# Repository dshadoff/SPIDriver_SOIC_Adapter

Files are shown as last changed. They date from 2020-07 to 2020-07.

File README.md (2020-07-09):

# SPIDriver SOIC Adapter board

While most of my boards are basically electrical things with some mechanical aspects,
some of them are primarily mechnical things with some electrical aspects. This board
is one of those.

I have an ExCamera Labs SPIDriver ( https://www.crowdsupply.com/excamera/spidriver ), and
I've been using it to read/write to various types of SPI memory chips; the hookup wires
provided with the unit are certainly multipupose, but they aren't optimized for connection
the SPIDriver to the SOIC in-circuit chip clip.

Before:
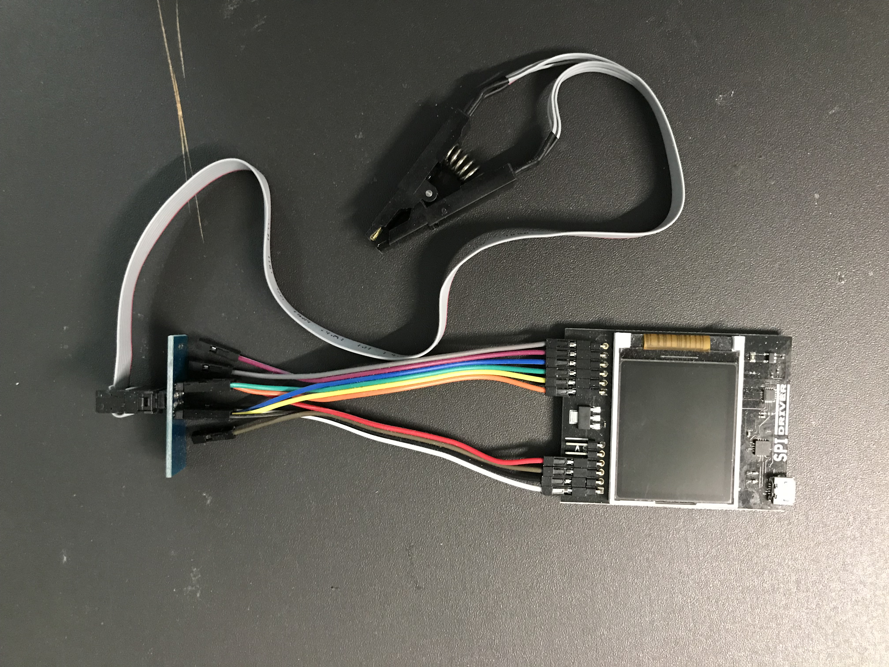
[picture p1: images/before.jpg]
Loose Wires


After:
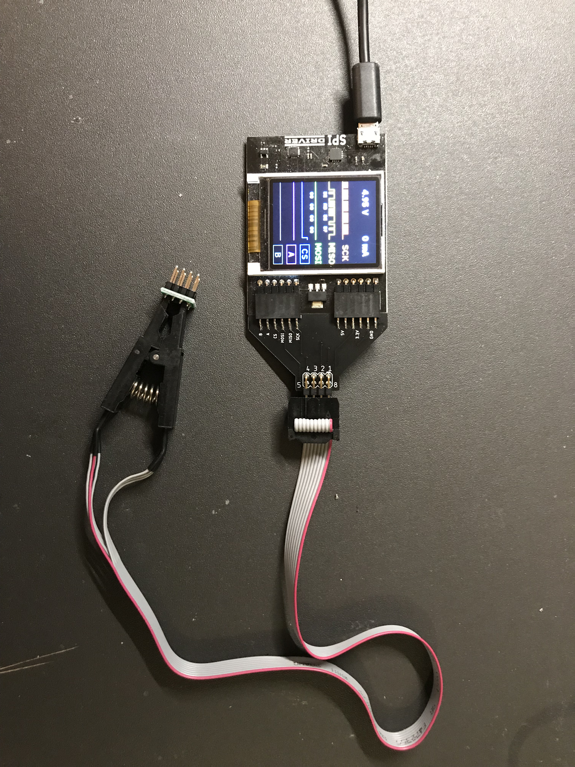
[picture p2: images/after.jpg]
Connector Board


Assembly is simple:
1. First attach the two Harwin M20-7910642R header sockets on the SPIDriver's headers.
(Link to part: https://www.mouser.ca/ProductDetail/Harwin/M20-7910642R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 )

2. Position the PC board right up agains the SPIDriver board, and attach clips to hold
it in place while soldering takes place.

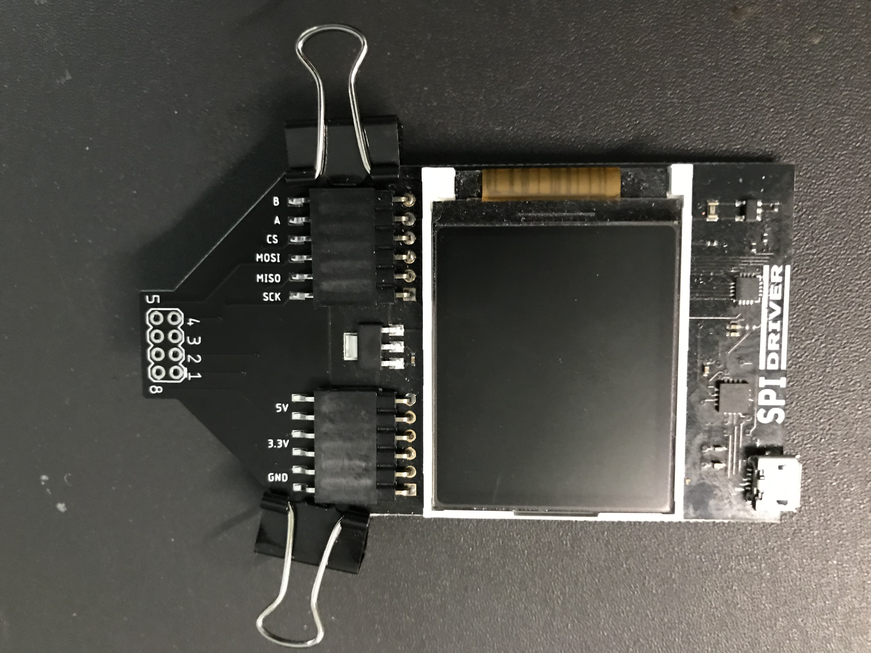
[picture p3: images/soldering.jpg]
Position Board


3. Add the 2-row headers and solder them in place.

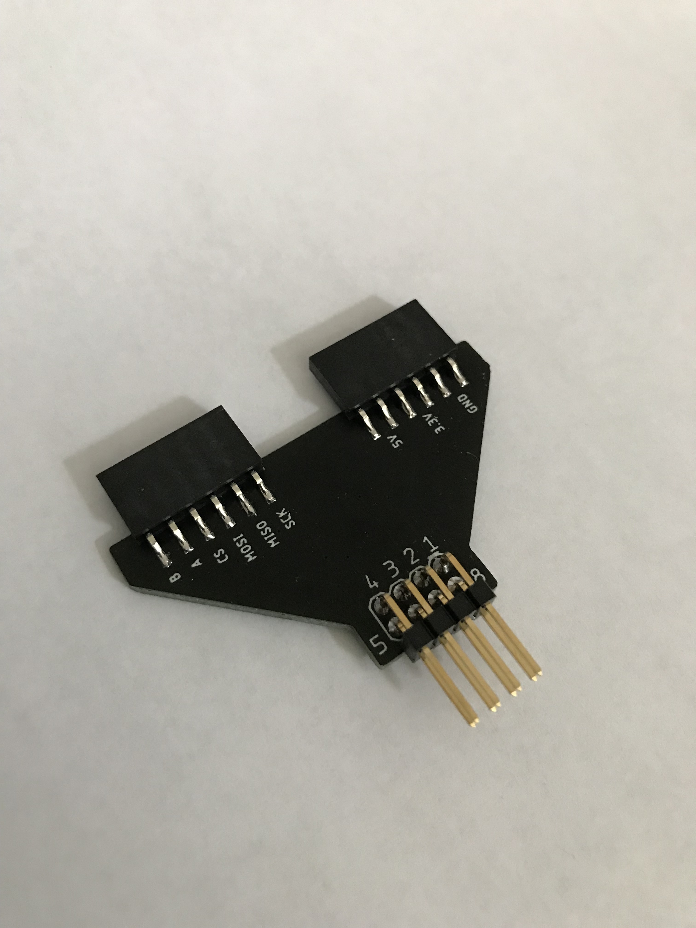
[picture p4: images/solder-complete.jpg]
Completed Board


I designed the board using the free version of EAGLE (2-layer, less than 100mm on both
X- and Y-axes).  The gerbers are included in this repository, in case you want to get your
own set made.

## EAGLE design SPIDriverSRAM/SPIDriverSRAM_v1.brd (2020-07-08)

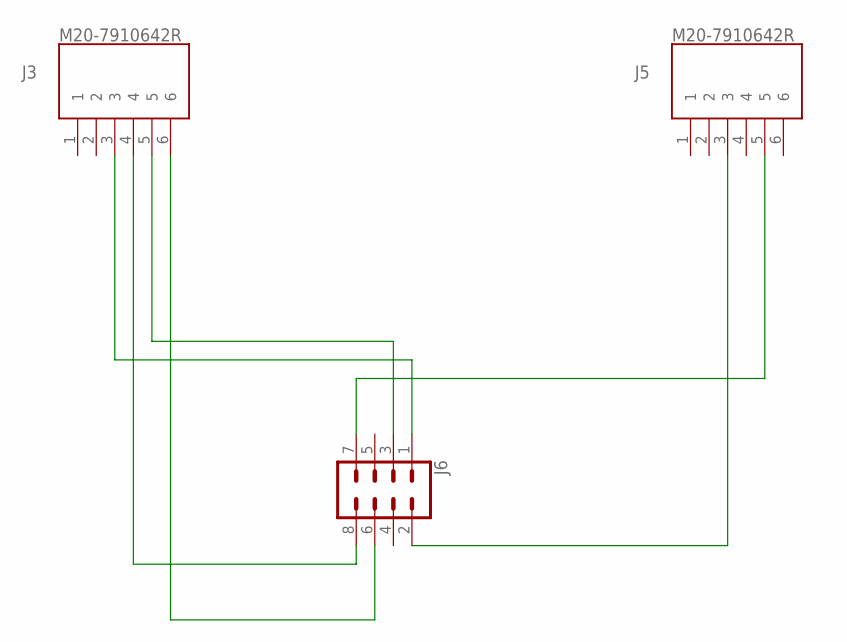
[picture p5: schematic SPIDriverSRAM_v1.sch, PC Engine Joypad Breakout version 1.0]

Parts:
J3, J5: M20-7910642R
J6: CONN_04X2; 2X4

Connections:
unnamed: J3.3, J6.1
unnamed: J3.5, J6.3
unnamed: J5.5, J6.7
unnamed: J5.3, J6.2
unnamed: J3.4, J6.8
unnamed: J3.6, J6.6

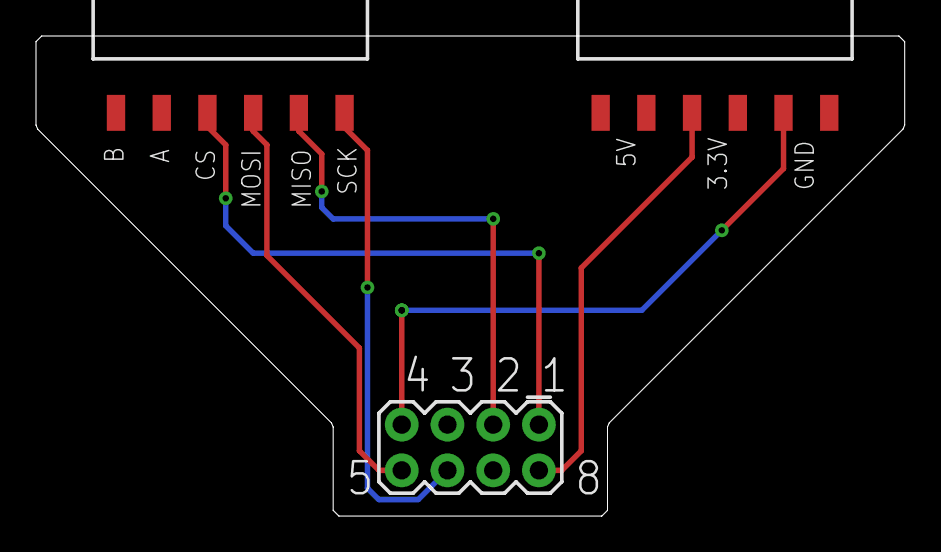
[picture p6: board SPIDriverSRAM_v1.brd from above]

Board: 2 copper layers, 48.3 x 26.7 mm, 3 parts (0 on the bottom side), 6 nets.

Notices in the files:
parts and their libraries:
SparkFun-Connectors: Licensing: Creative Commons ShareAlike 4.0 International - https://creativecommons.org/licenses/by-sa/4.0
